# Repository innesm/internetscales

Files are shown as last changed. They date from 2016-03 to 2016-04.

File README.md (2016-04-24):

# internetscales
Project to put some bathroom scales on the internet using an ESP8266

The idea here is that the MCU, an ESP8266, will use an ADC (MCP3008) to read the control lines of the LCD display of a set of bathroom scales, and upload weight readings to the internet.
The ESP8266 should be normally unpowered.
It gets woken up when stuff starts to happen on the control lines, then detects the weight reading by decoding what's displayed on the LCD.
Then, it uploads this to some cloud IoT thing and switches itself back off to save power.

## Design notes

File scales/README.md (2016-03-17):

# internetscales
Project to put some bathroom scales on the internet using an ESP8266

```
                                       +---------------------+
 +-----------+(B)    +-----------+ (A) |     +---------+     |
 |ESP8266    +-------+MCP3008    +-----+     |         |     |
 |mcu        |       |adc        |     |     +---------+     |
 +-----------+       +-----------+     |                     |
      |                                |    bathroom scale   |
      |                                |                     |
 +------------+                        |                     |
 |            |                        |                     |
 | The        |                        |                     |
 | Internet   |                        +---------------------+
 |            |
 |            |
 +------------+

(A) - read LCD display backplane and segment driver pins
(B) - decode LCD display to weight value.
      detect final weight reading.
      upload weight reading to the internet.
      
```

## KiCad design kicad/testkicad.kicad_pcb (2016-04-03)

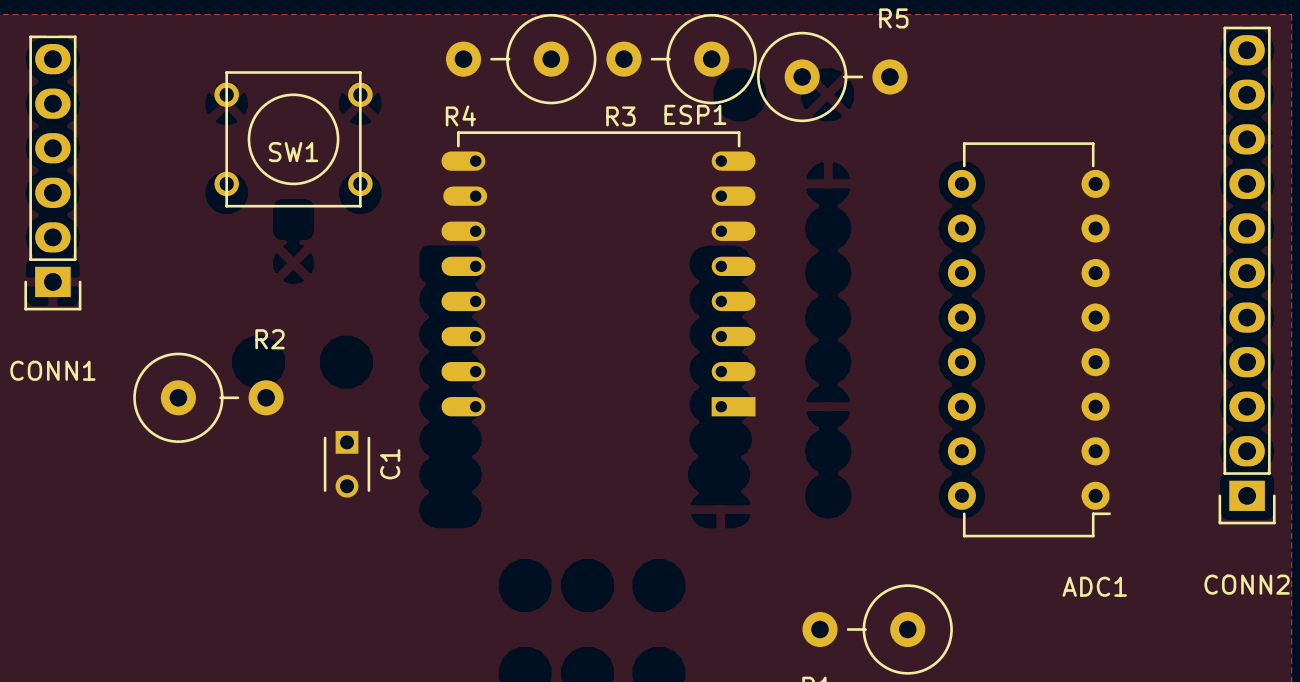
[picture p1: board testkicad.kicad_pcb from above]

Board: 2 copper layers, 11 parts (0 on the bottom side), 20 nets, no tracks yet.

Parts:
ADC1: MCP3008; DIP-16_W7.62mm
C1: 100nF; C_Disc_D3_P2.5
CONN1: FT232; Pin_Header_Straight_1x06
CONN2: SCALES_CONN; Pin_Header_Straight_1x11
ESP1: ESP-12
R1, R2, R3, R4, R5: 10K; Resistor_Vertical_RM5mm
SW1: RESET; SW_PUSH_SMALL

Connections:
+3V3: ADC1.15, ADC1.16, CONN1.3, ESP1.8, R1.1, R2.1, R3.1, R4.1
/CH_PD: ESP1.3, R1.2
/ESP_RX: CONN1.4, ESP1.15
/ESP_TX: CONN1.5, ESP1.16
/GPIO0: ESP1.12, R3.2
/GPIO2: ESP1.11, R4.2
/GPIO15: ADC1.10, ESP1.10, R5.1
/MISO: ADC1.12, ESP1.6
/MOSI: ADC1.11, ESP1.7
/REST: C1.1, ESP1.1, R2.2, SW1.1
/SPI_CLK: ADC1.13, ESP1.5
GND: ADC1.9, ADC1.14, C1.2, CONN1.1, CONN2.9, ESP1.9, R5.2, SW1.2
unnamed: ADC1.1, CONN2.1
unnamed: ADC1.2, CONN2.2
unnamed: ADC1.3, CONN2.3
unnamed: ADC1.4, CONN2.4
unnamed: ADC1.5, CONN2.5
unnamed: ADC1.6, CONN2.6
unnamed: ADC1.7, CONN2.7
unnamed: ADC1.8, CONN2.8

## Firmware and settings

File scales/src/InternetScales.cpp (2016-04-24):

#include <Arduino.h>

#include <ESP8266WiFi.h>
#include <ESP8266HTTPClient.h>

#include "WifiConfig.h"
#include "Internet.h"
#include "WeightDisplay.h"
#include "Bitmap.h"
#include "Countdown.h"
#include "mcp3008.h"

WeightDisplay screen;

// NODEMCU 1.0
//  gpio   |  function |  header pin label
//  GPIO12 |  MISO     |  "D6"
//  GPIO13 |  MOSI     |  "D7"
//  GPIO14 |  CLK      |  "D5"
//  GPIO15 |  CS       |  "D8"

int VOLTAGE_0_TO_1 = 200;  //between bias level 0 and 1
int VOLTAGE_2_TO_3 = 800; // between bias level 2 and 3

void readSegments(int backplane)
{
  for (int x = 0; x < SEGMENT_COUNT; ++x)
    screen.pixel(x, backplane) = read_analog(x + 1) > VOLTAGE_2_TO_3;
}

// tick time in micros tweaked to take into account the time
// taken to sample the segment lines.
const int ticktime = 1900;

void setup()
{
  pinMode(BUILTIN_LED, OUTPUT);
  init_mcp3008_spi();
  Serial.begin(74880);
  Serial.println(ESP.getResetReason());
  Serial.println(ESP.getResetInfo());
}

enum class state
{
  idle,
  waitingedge,
  capturing
};
state currstate = state::idle;

// helper for flashing an LED at different rates
Countdown cd(2000);
bool led;

void loop()
{
  // read backplane 0 'clock'
  int BP0 = read_analog(0);

  if (cd.done())
  {
    if (currstate == state::idle)
    {
      Serial.print("idle ");
      Serial.println(BP0);
    }
    else
    {
      Serial.print(".");
    }
    led = !led;
    digitalWrite(BUILTIN_LED, led);
  }

  switch(currstate)
  {
    case state::idle:

      if (BP0 > VOLTAGE_2_TO_3) // find fall to 0v
      {
        // start sampling frequently to catch the edge falling from 3 to 0 volts
        currstate = state::waitingedge;

        //flash info led more quickly
        cd.setTick(250);

        delayMicroseconds(50);
      }
      else if (BP0 < VOLTAGE_0_TO_1)
      {
        // check if zero for longer than a tick, meaning properly idle.
        // if so, sleep for a second.
        delay(2);
        int BP0 = read_analog(0);
        if (BP0 < VOLTAGE_0_TO_1)
        {
          Serial.println("back to sleep.");
          ESP.deepSleep(60000000, WAKE_RF_DEFAULT);//WAKE_RF_DISABLED); // a second (500,000 microseconds)
        }
      }
      else
      {
        delayMicroseconds(200);
      }

    case state::waitingedge:

      // find fall to zero, and start capturing a frame
      if (BP0 < VOLTAGE_0_TO_1)
      {
        currstate = state::capturing;
      }
      else
        delayMicroseconds(50);
      break;

    case state::capturing:

      // at frame start. begin capturing segment values.
      // read segments at each of these timepoints:
      // take readings in 3v peaks of segment signals (bp low)

      // delay to centre of tick
      delayMicroseconds(0.4 * ticktime);

      // sample segment lines during each backplane
      for (int bp = 0; bp < 4; ++bp)
      {
        readSegments(bp);

        if (bp < 3)
          delayMicroseconds(2 * ticktime);
      }

      // detect when display is indicating a "current weight"
      if (screen.is_current_weight())
      {
        // is display value valid?
        int weight_grams;
        if (screen.try_get_weight_grams(weight_grams))
        {
          Serial.print("Weight reading: ");
          Serial.print(weight_grams);
          Serial.println("g");

          digitalWrite(LED_BUILTIN, 1);
          // we captured a weight value.
          screen.try_get_weight_grams(weight_grams);
          //connect to wifi and upload
          post_to_thingspeak(weight_grams);
          //wait for scale to settle down
          Serial.println("back to sleep after logging a weight reading.");
          ESP.deepSleep(15000000, WAKE_RF_DEFAULT);//WAKE_RF_DISABLED); // a second (500,000 microseconds)

        }
        else
        {
          if (screen.is_current_weight() || screen.is_previous_weight())
          {
            Serial.println("Weight done, but not in kgs.");
          }
        }
      }

      // done capturing a frame
      currstate = state::idle;
      cd.setTick(2000);
  }
}

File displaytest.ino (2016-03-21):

#include <Wire.h>

#include <Adafruit_GFX.h>
#include <Adafruit_SSD1306.h>

#include <ESP8266WiFi.h>
#include <ESP8266HTTPClient.h>

#include <Adafruit_MQTT.h>
#include <Adafruit_MQTT_Client.h>

Adafruit_SSD1306 display;

//////////////////////////////////////////////////
// Generic pixel display
//////////////////////////////////////////////////
template<typename TPixel, size_t W, size_t H>
class Bitmap
{
  TPixel _pixels[W*H];
  
public:
  Bitmap()
  {
  }

  TPixel& pixel(size_t x, size_t y)
  {
    return _pixels[y * W + x];    
  } 
};

const int SEGMENT_COUNT = 7;
int VOLTAGE_0_TO_1 = 200;  //between bias level 0 and 1
int VOLTAGE_2_TO_3 = 800; // between bias level 2 and 3

////////////////////////////////////////////////
// Bathroom scales lcd display
////////////////////////////////////////////////
class WeightDisplay : public Bitmap<bool, SEGMENT_COUNT, 4>
{
  //7x4 'pixels'
  //cols:
  // 0-1 = tens digit
  // 2-3 = units digit (and decimal pt)
  // 4-5 = tenths digit
  // 6 = icons
  //  row 0 = KG
  //  row 1 = Lbs?
  //  row 2 = "current wt"
  //  row 3 = "previous wt"
  
public:

  int decode_digit(int digit, bool blank_is_zero=false)
  {
    // each digit is displayed in two adjacent columns
    int s0 = digit * 2;
    int s1 = digit * 2 + 1;
    
    return decode_7_segment(blank_is_zero,
      (pixel(s0,3) << 6) + 
      (pixel(s0,0) << 5) + 
      (pixel(s1,1) << 4) + 
      (pixel(s0,1) << 3) + 
      (pixel(s0,2) << 2) + 
      (pixel(s1,2) << 1) + 
      pixel(s1,0));
  }

//  String to_string()
//  {
//    String s;
//    s+= decode_digit(0);
//    s+= decode_digit(1);
//    s+= pixel(3, 3) ? "." : " ";
//    s+= decode_digit(2);
//    return s;
//  }

  bool is_current_weight()
  {
    return pixel(6, 2);
  }

  bool is_previous_weight()
  {
    return pixel(6, 3);
  }

  bool is_kilograms()
  {
    return pixel(6, 0);
  }

  bool try_get_weight_grams(int& grams)
  {
    grams = -1;

    //todo convert other units to grams
    if (!is_kilograms())
      return false;
      
    int tens = decode_digit(0, true);
    if (tens < 0)
      return false;
    grams = 10000 * tens;
    
    int units = decode_digit(1);
    if (units < 0)
      return false;
    grams += 1000 * units;
      
    int tenths = decode_digit(2);    
    if (tenths < 0)
      return false;
    grams += 100 * tenths;
    
    return true;
  }

  static int decode_7_segment(bool blank_is_zero, uint8_t bits)
  {
      if (bits == 0) return blank_is_zero ? 0 : -1;
      if (bits == 0b1110111) return 0;
      if (bits == 0b0010010) return 1;
      if (bits == 0b1011101) return 2;
      if (bits == 0b1011011) return 3;
      if (bits == 0b0111010) return 4;
      if (bits == 0b1101011) return 5;
      if (bits == 0b1101111) return 6;
      if (bits == 0b0010011) return 7;
      if (bits == 0b1111111) return 8;
      if (bits == 0b1111011) return 9;
      return -2;
  }
};

struct Pt
{
  int x, y;
};

Pt getCursorPos()
{
  Pt p;
  p.x = display.getCursorX();
  p.y = display.getCursorY();
  return p;
}

WeightDisplay screen;

void introDisplay()
{
  display.setTextSize(2);
  display.setTextWrap(true);
  
  display.setTextColor(WHITE, BLACK);
  display.println("hello");
  display.setTextSize(1);
  display.print(__DATE__);
  display.print(" ");
  display.println(__TIME__);
  String reset_reason = ESP.getResetReason();
  display.print("RST:");
  display.println(reset_reason);

  if (reset_reason == "Exception")
  {
    display.setTextSize(2);
    display.println("[press reset]");
    display.display();
    while(1){delay(1000);}
  }
  display.display();
}

void beginDisplay()
{
  display.begin(SSD1306_SWITCHCAPVCC, 0x3C); 
  display.clearDisplay();
  introDisplay();
}

uint8_t reversebits(uint8_t b)
{
  uint8_t r = 0;
  for (int idx = 0; idx < 8; idx++)
  if (b & bit(idx))
    r |= bit(7 - idx);
  return r;
}

void init_spi()
{
  SPI.setHwCs(true);
  SPI.begin();
  SPI.beginTransaction(SPISettings(SPI_CLOCK_DIV8, MSBFIRST, SPI_MODE0));
}

// Read channel from MCP3008 using SPI
int read_analog(int channel)
{
  uint8_t send_bytes[] = {0xC0 + (channel << 3), 0, 0, 0};
  uint8_t recv_bytes[4];
  SPI.transferBytes(send_bytes, recv_bytes, 4);
  uint8_t b3 = reversebits(recv_bytes[3]);
  uint8_t b2 = reversebits(recv_bytes[2]);
  return (b3 << 8) + b2;
}

///////////////////////////////
// Simple timer helper
///////////////////////////////
class Countdown
{
  int starttime;
  int tick;
 
 public:
  Countdown(int d) : starttime(millis()), tick(d)
  {
  }

  void setTick(int newTick)
  {
    tick = newTick;
  }
  
  bool done()
  {
    int elapsed = millis() - starttime;
    if (elapsed > tick)
    {
      starttime = millis();
      return true;
    }
    return false;
  } 
};

enum class state
{
  idle,
  waitingedge,
  capturing
};

state currstate = state::idle;

void readSegments(int backplane)
{
  for (int x = 0; x < SEGMENT_COUNT; ++x)
    screen.pixel(x, backplane) = read_analog(x + 1) > VOLTAGE_2_TO_3;
}

void fillRect(int16_t x, int16_t y, int16_t w, int16_t h, uint16_t color)
{
  for (int row = y; row < y + h; ++row)
    display.drawFastHLine(x, row, w, color);
}

void hatchRect(int16_t x, int16_t y, int16_t w, int16_t h)
{
  for (int row = y; row < y + h; ++row)
    for (int col = x; col < x + w; ++col)
      display.drawPixel(col, row, ((col + row) % 2 == 0) ? BLACK : WHITE);
}

void drawPixel(int16_t x, int16_t y, int16_t w, int16_t h, bool set)
{
  if (set)
  {
    hatchRect(x, y, w-1, h-1);    
    display.drawFastHLine(x+1, y+h-1, w-1, BLACK);
    display.drawFastVLine(x+w-1, y+1, h-1, BLACK);
  }
  else
  {
    fillRect(x, y, w, h, WHITE);
  }
}

void printSegmentReadings()
{
  display.clearDisplay();
  display.setTextSize(1);
  display.setCursor(0,0);

  int w = 5;
  int h = 6;
  int t = 2;

  fillRect(0, 0, 128, 4 * (h+1) + 4, WHITE);
  
  for (int y = 0; y < 4; ++y)
  {
    int l = 2;
    for (int x = 0; x < SEGMENT_COUNT; ++x)
    {
      if (screen.pixel(x, y))
        drawPixel(l, t + y * (h+1), w, h, true);
      l += w+1;
      if (x % 2 == 1)//digits spacing
        l+= 2;
    }
  }
  
  display.setCursor(0, 4 * (h+1) + 4 + 2);
  display.display();
}

// helper for flashing an LED at different rates
Countdown cd(2000);

// info led state
bool led;

// tick time in micros tweaked to take into account the time
// taken to sample the segment lines.
const int ticktime = 1900;
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
